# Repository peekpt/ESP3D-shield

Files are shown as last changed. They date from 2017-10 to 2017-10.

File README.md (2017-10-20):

## ESP3D-SHIELD
ESP3D - it's a software based on ESP8266 module to give Wi-Fi capabilities 3D Printers.

ESP3D-SHIELD - it's an adapter to connect a 3D printer AUX-1 port

--

*ESP3D info:*

* [ESP3D](https://github.com/luc-github/ESP3D)

* [ESP3D WEBUI](https://github.com/luc-github/ESP3D-WEBUI)

--

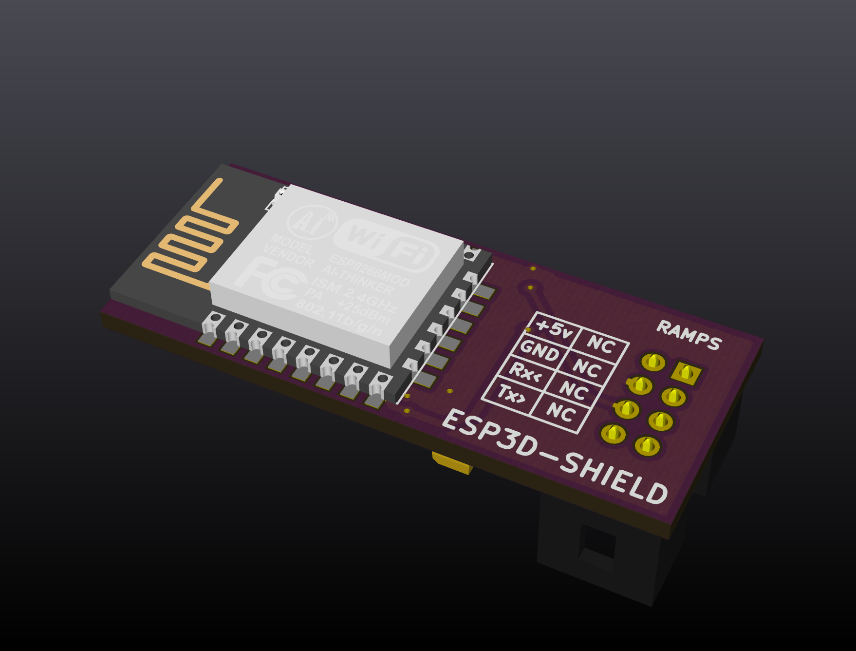
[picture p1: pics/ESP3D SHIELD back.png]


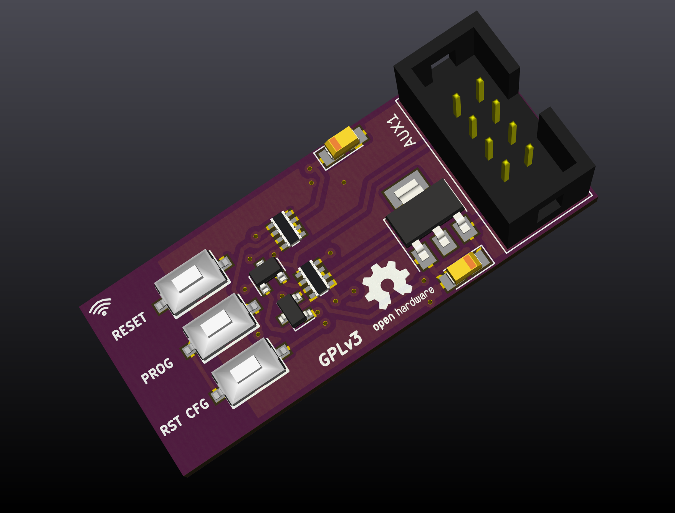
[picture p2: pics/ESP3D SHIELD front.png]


*WIP*

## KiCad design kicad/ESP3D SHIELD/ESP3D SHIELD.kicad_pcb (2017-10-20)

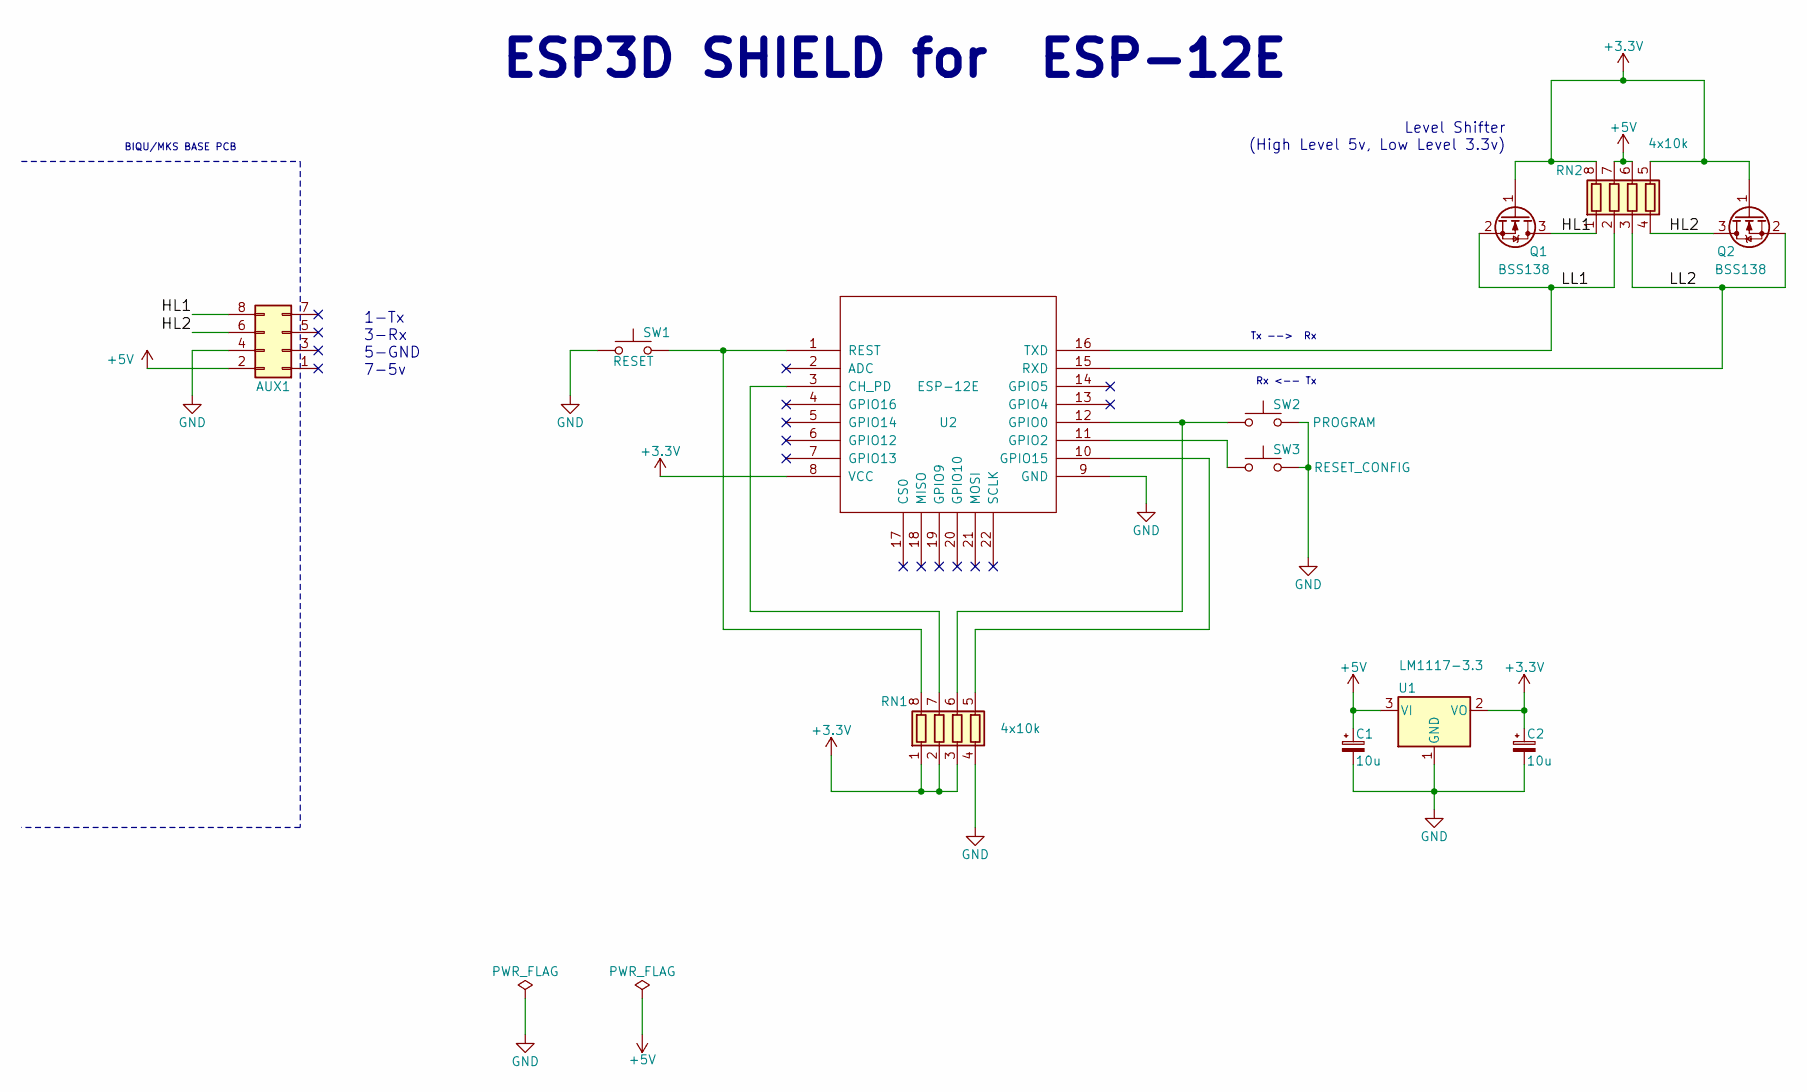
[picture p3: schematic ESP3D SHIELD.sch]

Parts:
AUX1: Conn_02x04_Odd_Even; Socket_Strip_Straight_2x04_Pitch2.54mm
C1, C2: 10u; CP_Tantalum_Case-A_EIA-3216-18_Reflow
Q1, Q2: BSS138; SOT-23
RN1, RN2: 4x10k; R_Array_Concave_4x0603
SW1: RESET; smd_push
SW2: PROGRAM; smd_push
SW3: RESET_CONFIG; smd_push
U1: LM1117-3.3; SOT-223
U2: ESP-12E; ESP-12E_SMD

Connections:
+3V3: C2.1, Q1.1 (G), Q2.1 (G), RN1.1 (R1.1), RN1.2 (R2.1), RN1.3 (R3.1), RN2.5 (R4.2), RN2.8 (R1.2), U1.2 (VO), U2.8 (VCC)
+5V: AUX1.2, C1.1, RN2.6 (R3.2), RN2.7 (R2.2), U1.3 (VI)
/HL1: AUX1.8, Q1.3 (D), RN2.1 (R1.1)
/HL2: AUX1.6, Q2.3 (D), RN2.4 (R4.1)
/LL1: Q1.2 (S), RN2.2 (R2.1), U2.16 (TXD)
/LL2: Q2.2 (S), RN2.3 (R3.1), U2.15 (RXD)
GND: AUX1.4, C1.2, C2.2, RN1.4 (R4.1), SW1.1, SW2.2, SW3.2, U1.1 (GND), U2.9 (GND)
unnamed: RN1.5 (R4.2), U2.10 (GPIO15)
unnamed: RN1.6 (R3.2), SW2.1, U2.12 (GPIO0)
unnamed: RN1.7 (R2.2), U2.3 (CH_PD)
unnamed: RN1.8 (R1.2), SW1.2, U2.1 (REST)
unnamed: SW3.1, U2.11 (GPIO2)

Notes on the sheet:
Level Shifter (High Level 5v, Low Level 3.3v)
1-Tx 3-Rx 5-GND 7-5v
BIQU/MKS BASE PCB
Tx --> Rx
Rx <-- Tx
ESP3D SHIELD for ESP-12E

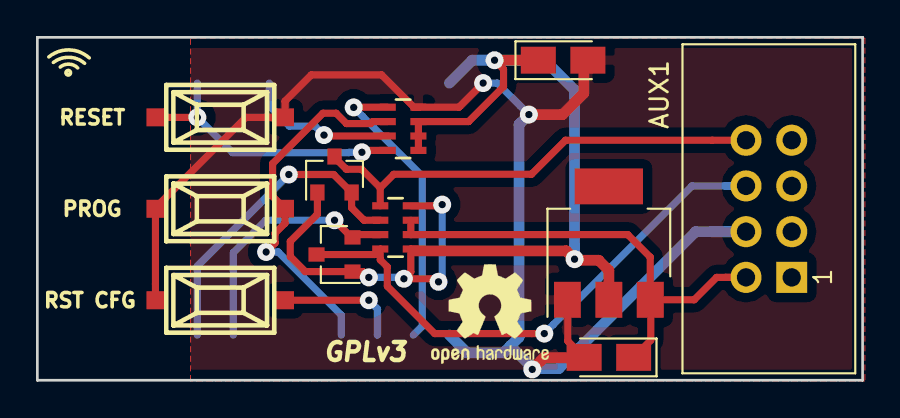
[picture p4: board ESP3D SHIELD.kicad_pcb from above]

Board: 2 copper layers, 45.8 x 19.1 mm, 12 parts (1 on the bottom side), 12 nets.

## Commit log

2017-10-20 rev A
    [ESP3D SHIELD-B.Cu.gbl, ESP3D SHIELD-B.Mask.gbs, ESP3D SHIELD-B.Paste.gbp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]
2017-10-20 connector is now IDC , bigger board
    [ESP3D SHIELD.kicad_pcb, ESP3D SHIELD.sch, _saved_ESP3D SHIELD.sch]
2017-10-20 revB final
    [ESP3D SHIELD-B.Cu.gbl, ESP3D SHIELD-B.Mask.gbs, ESP3D SHIELD-B.Paste.gbp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]
2017-10-20 revB final2
    [ESP3D SHIELD-Margin.gbr]

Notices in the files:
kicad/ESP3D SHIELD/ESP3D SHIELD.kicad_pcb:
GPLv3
